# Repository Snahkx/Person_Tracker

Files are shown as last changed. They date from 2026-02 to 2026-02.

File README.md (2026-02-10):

# Real-Time Vision-Based Person Tracking with Pan–Tilt Control

This project is a hands-on exploration of real-time computer vision,
embedded control, and mechanical design. The system detects a human target
in a camera feed and physically reorients the camera using a pan–tilt
mechanism to keep the target centered.

It was built as an end-to-end system: from camera input, through control
logic, all the way to custom hardware.

---

Made in Collaboration with Ayrton Wong, AyrtonW312 on Github.

---

## Why This Project Exists

I wanted to build something that closed the loop between perception and
physical motion. Rather than stopping at detection on a screen, this
project forces the software to deal with the messiness of real hardware:
noise, latency, jitter, and failure modes.

The goal was not perfection, but understanding.

---

## What the System Does

- Captures live video on a Raspberry Pi
- Detects and tracks a human target
- Computes image-space error relative to the frame center
- Converts that error into pan–tilt servo commands
- Physically moves the camera to follow the target

All of this runs in real time on embedded hardware.

---

## System Structure

The system is organized into three layers:
- Vision (what do I see?)
- Control (how should I move?)
- Hardware (how do I move safely?)

Each layer is deliberately kept simple and isolated.

For details, see:
- [`docs/architecture.md`](docs/architecture.md)
- [`docs/design-decisions.md`](docs/design-decisions.md)

---

## Hardware

The camera is mounted on a custom-designed pan–tilt platform modeled in
SolidWorks. The design focuses on alignment, stiffness, and ease of
iteration using 3D-printed components.

📁 Hardware files, drawings, and assembly: [`hardware/`](hardware/)

---

## Validation

The system was tested on physical Raspberry Pi hardware with a servo-driven
pan–tilt platform. Testing focused on:
- Stability near the image center
- Smooth target reacquisition
- Safe behavior during target loss

---

## Current State

The core system is complete and documented. Demo media and annotated
screenshots will be added once hardware access is available.

---

## Future Directions

This project is intentionally extensible. Possible next steps include:
- Predictive filtering for smoother motion
- Multi-target tracking
- ROS2 integration
- Hardware acceleration for vision processing

https://ibrahimmansur4.medium.com/integrating-opencv-with-ros2-a-comprehensive-guide-to-computer-vision-in-robotics-66b97fa2de92

---

## Repo Guide

- `src/` – vision, control, and runtime code  
- `hardware/` – Files, drawings, and Assembly.
- `docs/` – architecture and design documentation  
- `demo/` – demo media (to be added)

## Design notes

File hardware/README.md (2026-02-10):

# Hardware Design – Pan–Tilt Tracking Platform

## Overview
This hardware system supports a camera-based real-time tracking pipeline by providing
a two-axis pan–tilt mechanism driven by SG90 servos. The design prioritizes stability,
repeatability, and ease of integration with Raspberry Pi-based control software.

## Components
- 2× SG90 servos (pan + tilt)
- Raspberry Pi camera module 
- Custom-designed 3D printed pan–tilt setup (SolidWorks)
- Fasteners (M3 hardware)
- Base mount (desk)

## Mechanical Architecture
The system consists of a fixed base, a pan stage driven by a horizontal-axis servo,
and a tilt stage mounted orthogonally to allow vertical tracking. The camera bracket
is aligned to minimize offset between optical axis and rotation axes.

## CAD Files
- Native SolidWorks files: `hardware/cad/`
- Neutral exports (STL): `hardware/exports/`
- Manufacturing drawings: `hardware/drawings/`

## Design Considerations
- Minimized backlash in servo mounts + DFA 
- Camera alignment to reduce control error + DFA
- Structural stiffness to limit vibration + DFA
- Fastener accessibility for rapid iteration + DFA

## Assembly
See exploded view for assembly below, schematics in other files.

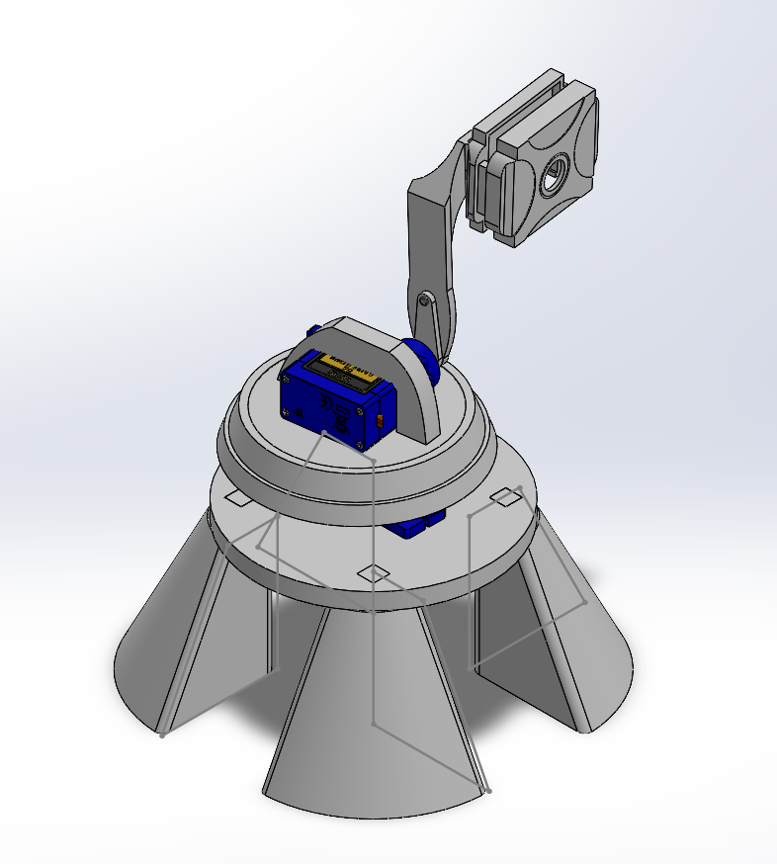
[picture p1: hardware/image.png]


## Future Improvements
- Bearing-supported pan axis
- Higher-torque digital servos
- Enclosure for cable management
- Vibration damping

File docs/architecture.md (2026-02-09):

# System Architecture

This document describes the high-level architecture of the real-time
vision-based tracking system, including subsystem boundaries, data flow,
and design rationale.

The system was intentionally structured to separate perception, control,
and hardware interaction, allowing each layer to be developed, tested,
and reasoned about independently.

---

## High-Level Overview

At a high level, the system operates as a closed-loop feedback controller:

1. Capture a video frame from the camera
2. Detect and localize a target in image space
3. Compute positional error relative to the image center
4. Convert error into pan–tilt motion commands
5. Actuate servos to reorient the camera
6. Repeat at real-time frequency

This loop runs continuously on Raspberry Pi hardware.

---

## Subsystem Decomposition

The system is divided into three primary subsystems:

- Vision Pipeline
- Control Layer
- Hardware Interface

Each subsystem has a clearly defined responsibility and communicates
through simple, explicit interfaces.

---

## Vision Pipeline

**Responsibility:**  
Convert raw camera frames into a target position in pixel coordinates.

**Key components:**
- Camera abstraction for frame acquisition
- Detection modules (person / face / colour)
- Target selection and bounding box extraction
- Overlay rendering for diagnostics

The vision pipeline outputs:
- Target centroid `(x, y)` in image space
- Bounding box dimensions
- A validity signal indicating whether a target is currently tracked

The pipeline is designed to be stateless between frames, which simplifies
debugging and allows tracking modes to be swapped without affecting
downstream control logic.

---

## Control Layer

**Responsibility:**  
Translate image-space error into stable, physically safe servo commands.

The control layer receives:
- Horizontal and vertical pixel error
- Target validity state

It outputs:
- Pan and tilt servo pulse-width updates

### Error Computation

Error is computed as the difference between the target centroid and the
image center. This representation is intuitive, camera-agnostic, and
directly maps to pan–tilt motion.

### Deadband Logic

A configurable deadband is applied around the image center to suppress
small corrections caused by detection noise. This prevents servo jitter
and oscillation when the target is already approximately centered.

### Rate Limiting and Smoothing

To avoid aggressive motion when the target is far from center, the control
layer scales movement based on error magnitude. Large errors result in
faster motion, while small errors result in slower, finer adjustments.

---

## Hardware Interface

**Responsibility:**  
Safely translate control commands into physical motion.

The hardware interface:
- Initializes the pigpio connection
- Configures servo pulse-width limits
- Enforces minimum and maximum travel bounds
- Provides a clean shutdown path

Hardware availability is treated as a runtime condition rather than a
compile-time assumption. If the pigpio daemon is unavailable, the system
fails gracefully without crashing the vision pipeline.

---

## Configuration Strategy

All tunable parameters (servo limits, deadband size, detection thresholds)
are centralized in configuration files.

This approach:
- Eliminates hard-coded constants
- Enables rapid tuning without code changes
- Allows environment-specific overrides
- Makes system behavior explicit and auditable

---

### Interface Contracts (What each layer guarantees)

- Vision → Control:
  - Provides `(dx, dy)` pixel error from frame center and a `valid` flag.
  - Guarantees coordinates are in image space using the same frame resolution.

- Control → Hardware:
  - Provides bounded PWM pulse widths (µs) for pan and tilt channels.
  - Guarantees safety limits are enforced before commanding servos.

- Hardware → Vision:
  - Motion changes camera orientation; vision loop compensates continuously.
  - No direct feedback from servos is assumed (open-loop actuation).
  
  ---

## Architecture Diagram (End-to-End)

```text
┌───────────────────────────────────────────────────────────────┐
│                         Operator / User                        │
│  - Launches runtime (python main.py)                           │
│  - Observes overlay + tuning feedback                          │
└───────────────────────────────────────────────────────────────┘
                          │  Launch / Config
                          ▼
┌───────────────────────────────────────────────────────────────┐
│                       Runtime: main.py                         │
│  Application Loop:                                              │
│  - frame = Camera.read()                                        │
│  - result = tracker.process(frame)                              │
│  - compute pixel error vs frame center                          │
│  - update PanTiltController (if enabled)                        │
│  - draw overlay diagnostics                                     │
└───────────────────────────────────────────────────────────────┘
                          │  Frame + detection results
                          ▼
┌───────────────────────────────────────────────────────────────┐
│                    Vision Subsystem (src/vision)               │
│  Camera                                                        │
│  - Pi Camera / USB capture                                     │
│  - resolution + FPS tuning                                     │
│                                                               │
│  Trackers (person / face / colour)                              │
│  - detection + bounding box extraction                          │
│  - target selection (single target)                             │
│  - outputs centroid (x,y), bbox, valid flag                     │
└───────────────────────────────────────────────────────────────┘
                          │  Pixel error (dx, dy)
                          ▼
┌───────────────────────────────────────────────────────────────┐
│                 Control Subsystem (src/servo)                  │
│  PanTiltController                                              │
│  - deadband (jitter suppression near center)                    │
│  - error → step/velocity mapping                                │
│  - rate limiting / smoothing for stability                      │
│  - enforces min/max pulse widths (safe bounds)                  │
│                                                               │
│  pigpio Interface                                               │
│  - connects to pigpio daemon                                    │
│  - sends PWM pulse widths to GPIO pins                          │
└───────────────────────────────────────────────────────────────┘
                          │  PWM (pulse width in µs)
                          ▼
┌───────────────────────────────────────────────────────────────┐
│                        Hardware Platform                        │
│  Pan Servo (Yaw)                 Tilt Servo (Pitch)             │
│  - horizontal rotation           - vertical rotation             │
│             \                         /                          │
│              \                       /                           │
│               ▼                     ▼                            │
│               Pan–Tilt Mechanical Assembly                       │
│        (SolidWorks CAD + drawings in /hardware)                  │
│                               │                                 │
│                               ▼                                 │
│                           Camera Mount                           │
└───────────────────────────────────────────────────────────────┘

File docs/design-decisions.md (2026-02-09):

# Design Decisions & Rationale

This document captures the key design decisions made during development,
including alternatives considered and tradeoffs accepted.

The goal is not to claim optimality, but to document reasoning.

---

## Choice of Platform: Raspberry Pi

The Raspberry Pi was selected as the target platform due to:
- Widespread availability
- Adequate performance for real-time vision tasks
- Direct GPIO access for servo control
- Strong ecosystem support
- Beginner introduction to bash, linux, and terminal cmds

Resource constraints influenced several downstream design decisions,
particularly around processing frequency and algorithm complexity.

---

## Vision Library: OpenCV

OpenCV was chosen for its:
- Mature and well-documented API
- Real-time performance on ARM platforms
- Broad support for classical vision techniques
- Ease of integration with Python
- Default Libraries

Deep learning–based detectors were intentionally avoided in the initial
implementation to reduce system complexity and hardware dependency.

---

## Control Strategy: Classical Feedback Control

A classical feedback control approach was chosen over more advanced
predictive methods.

Reasons:
- Transparent behavior that is easy to reason about
- Minimal tuning complexity
- Robustness to partial or noisy detections
- Suitability for low-latency embedded systems

This decision favored reliability and interpretability over theoretical
optimality.

---

## Deadband-Based Stabilization

Initial testing revealed servo jitter when the target hovered near the
image center. Rather than filtering detection output aggressively, a
deadband was introduced at the control level.

This approach:
- Directly addresses the symptom (micro-corrections)
- Preserves responsiveness for larger errors
- Simplifies tuning

---

## pigpio for Servo Control

pigpio was selected instead of software PWM due to:
- Hardware-timed pulse generation
- Reduced jitter under system load
- Precise pulse-width control

The dependency on a background daemon was accepted in exchange for
improved control stability.

---

## Modular Tracking Modes

Tracking modes (person, face, colour) were implemented as modular units
sharing a common interface.

This decision:
- Simplifies experimentation
- Avoids entangling detection logic with control logic
- Enables rapid switching without structural changes

---

## Configuration-Driven Design

Centralized configuration files were used to avoid embedding tuning
parameters directly in code.

Benefits:
- Faster iteration during testing
- Clear separation between logic and parameters
- Easier portability across hardware setups

---

## Error Handling Philosophy

Rather than failing loudly when hardware components are unavailable,
the system degrades gracefully.

This reflects a practical development reality: hardware is not always
available, but software iteration should continue regardless.

---

## Known Limitations

- No predictive tracking or velocity estimation
- Single-target assumption
- Limited robustness under extreme lighting conditions

These limitations were consciously accepted to prioritize system clarity
and stability.

---

## Reflection

Many of these decisions prioritize understandability and robustness over
maximum performance. This aligns with the project’s goal as a learning
platform and a foundation for future expansion rather than a production
deployment.

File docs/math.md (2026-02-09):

# Distance Estimation (Monocular)

This document describes how `DistanceEstimator` estimates the distance between
the camera and a tracked target using a **single monocular camera**. The approach
uses a pinhole camera approximation, one-time calibration, and exponential
smoothing for real-time stability.

---

## Signal Processing Pipeline

Goal: estimate distance to target (cm) from a detected bounding box width (px).

Camera Frame
↓
Target Detection / Tracking
↓
Bounding Box Width (px)
↓
Pinhole Distance Model
↓
Exponential Smoothing
↓
Distance Estimate (cm)

---

## Core Model: Pinhole Camera Approximation

The estimator assumes a pinhole camera model where the apparent width of an
object in the image is inversely proportional to its distance from the camera.

distance_cm = (known_width_cm * focal_length_px) / bbox_width_px

Where:
- `known_width_cm` = real-world width of the target (KNOWN_TARGET_WIDTH_CM)
- `focal_length_px` = camera focal length in pixel units (FOCAL_LENGTH_PX)
- `bbox_width_px` = observed bounding box width in pixels

Interpretation:
- Larger bounding box → target is closer
- Smaller bounding box → target is farther

---

## Calibration (Estimating Focal Length in Pixels)

Because focal length in pixel units depends on camera intrinsics and resolution,
it is estimated once using a known-distance calibration.

focal_length_px = (bbox_width_px * calib_distance_cm) / known_width_cm

Where:
- `calib_distance_cm` = known distance during calibration (CALIB_DISTANCE_CM)
- `bbox_width_px` = bounding box width measured at that distance
- `known_width_cm` = real-world target width

---

### Practical Calibration Procedure

1. Place the target at a known distance (e.g. 50 cm).
2. Run the tracker and measure `bbox_width_px`.
3. Call `calibrate(bbox_width_px)` once.
4. Store the resulting `FOCAL_LENGTH_PX` in the config for repeatable runs.

---

### Notes / Assumptions

- Assumes the target’s effective width is consistent and roughly planar to the camera.
- Changing camera resolution changes pixel focal length.
- Recalibrate if camera resolution or lens changes.

---

## Distance Estimation (Runtime)

Once calibrated, distance is computed every frame using the pinhole model:

raw_distance_cm = (known_width_cm * focal_length_px) / bbox_width_px

If focal length is unknown or `bbox_width_px <= 0`, the estimator returns `None`
to avoid invalid results.

---

## Smoothing (Low-Pass Filter)

Raw distance estimates fluctuate due to detection noise (lighting, occlusion,
bounding box jitter). To stabilize the output, exponential smoothing is applied.

smoothed_distance =
(1 - alpha) * previous_distance + alpha * current_distance

Where:
- `alpha` = smoothing factor (DIST_SMOOTH_ALPHA)
- Lower alpha → smoother but slower response
- Higher alpha → faster response but noisier

Implementation detail:
- On the first valid estimate, the smoothed value is initialized directly.

---

## Configuration Reference

| Parameter | Config Key | Default | Description |
|---|---|---|---|
| Target width (cm) | KNOWN_TARGET_WIDTH_CM | 16.0 | Assumed real-world target width |
| Calibration distance (cm) | CALIB_DISTANCE_CM | 50.0 | Known distance for calibration |
| Focal length (px) | FOCAL_LENGTH_PX | None | Computed once via calibration |
| Smoothing factor | DIST_SMOOTH_ALPHA | 0.25 | Exponential smoothing strength |

---

## Failure Conditions

The estimator returns `None` when:
- Focal length has not been calibrated
- Bounding box width is zero or invalid

This prevents divide-by-zero and meaningless distance values.

---

## Limitations

- Distance accuracy depends on the correctness of `known_width_cm`
- Bounding box width changes with target orientation (e.g. rotation)
- Monocular depth estimation is inherently approximate
- Not suitable for precise ranging or safety-critical decisions

Despite these limitations, the estimator provides a lightweight and
real-time distance approximation suitable for visualization and
coarse behavior logic.

---

## Future Improvements

- Height-based estimation (more stable for upright people)
- Keypoint-based distance instead of bounding box width
- Kalman filtering for predictive smoothing
- Multi-point calibration curve

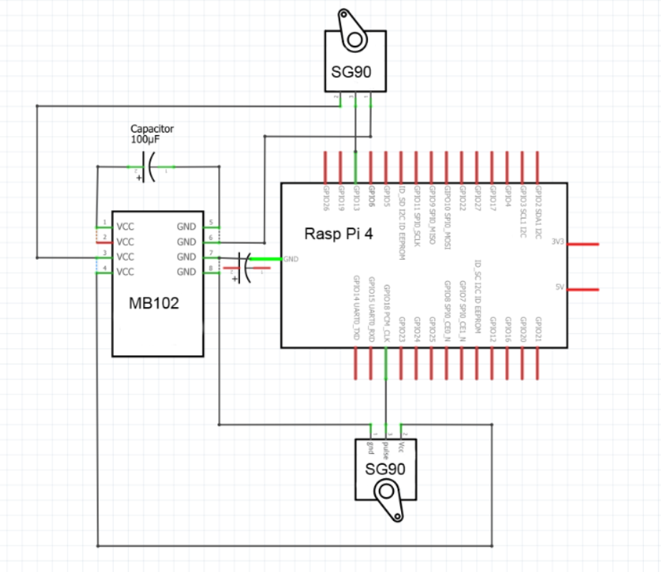
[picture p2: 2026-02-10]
hardware/wiring/schematic.png

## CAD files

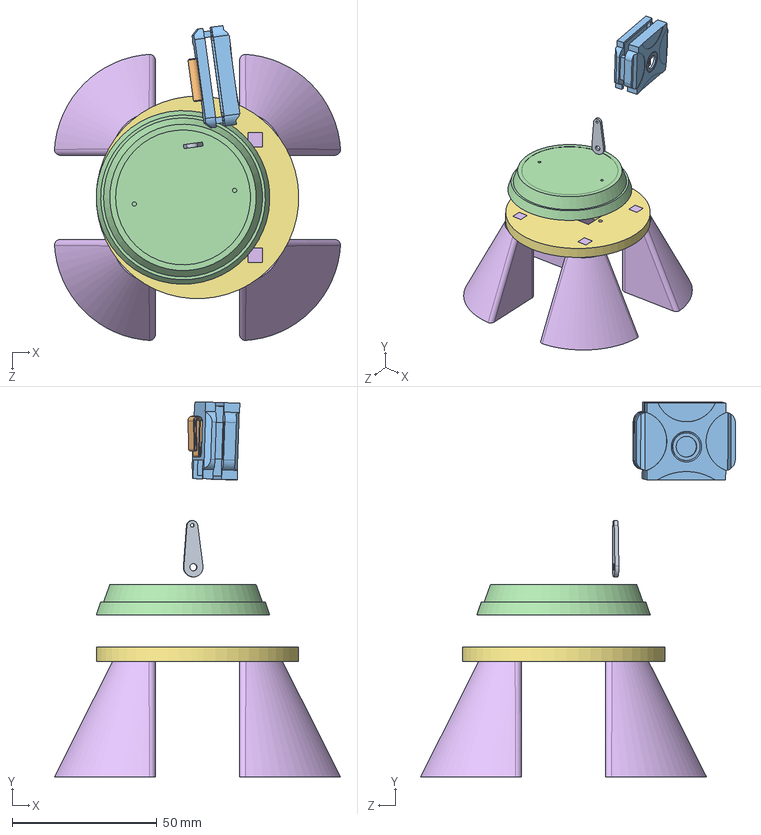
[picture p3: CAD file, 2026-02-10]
hardware/drawings/Assembly.SLDASM
98.9 x 129.6 x 108.8 mm
basePlateservo
legreal x 4
pimainWheel
surface2
cambox
camConnector
Servo Boomerang sg9

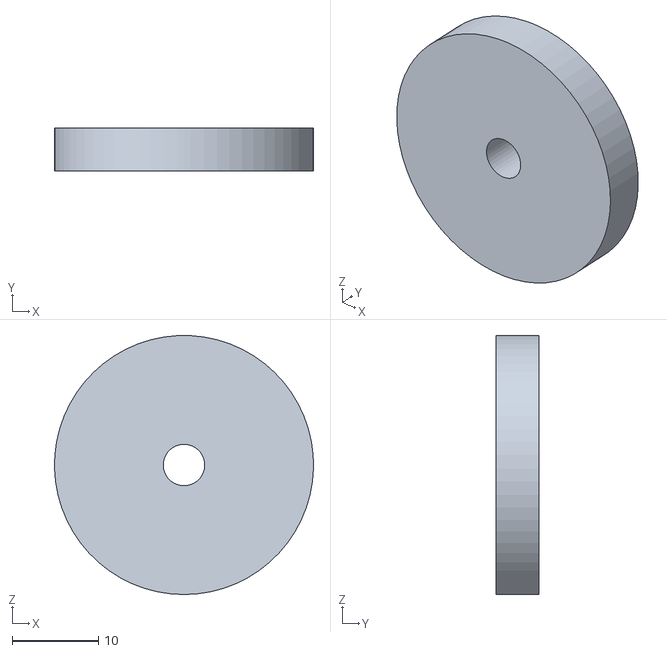
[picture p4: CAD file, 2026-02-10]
hardware/exports/pimainWheel.STL
30.0 x 5.00 x 30.0

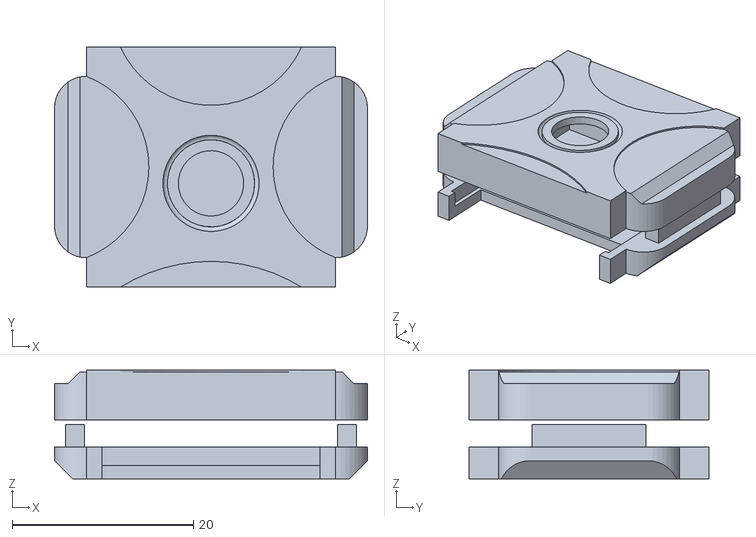
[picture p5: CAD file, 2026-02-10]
hardware/exports/cambox.STL
34.5 x 26.5 x 12.0

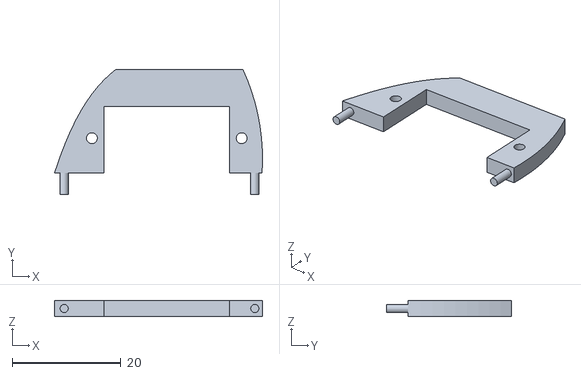
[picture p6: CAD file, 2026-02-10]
hardware/exports/handle.STL
38.2 x 23.0 x 3.00

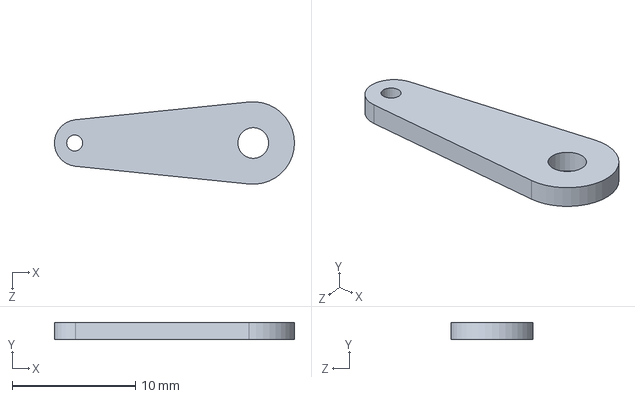
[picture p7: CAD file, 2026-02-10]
hardware/drawings/Servo Boomerang sg9.SLDPRT
19.5 x 1.40 x 6.69 mm

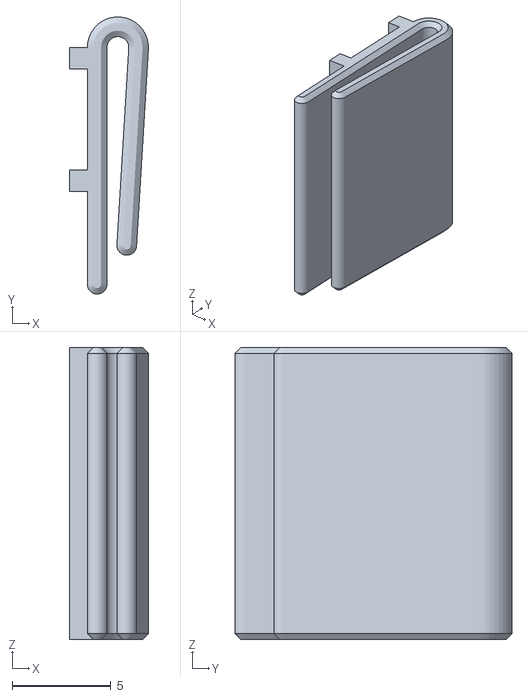
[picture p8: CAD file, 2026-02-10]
hardware/exports/camConnector.STL
4.00 x 14.0 x 14.8

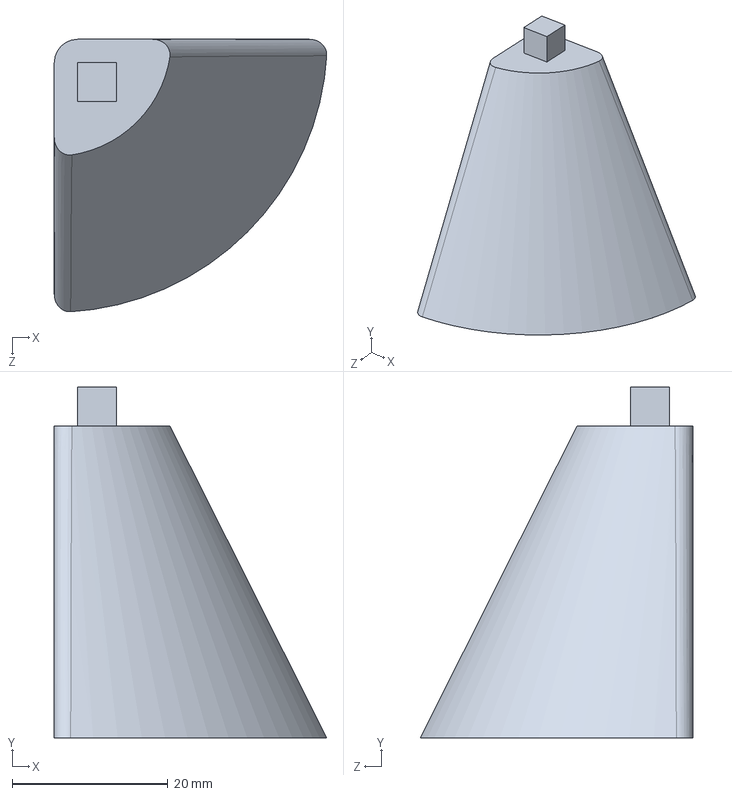
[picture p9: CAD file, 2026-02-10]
hardware/drawings/legreal.SLDPRT
34.9 x 45.0 x 34.9 mm

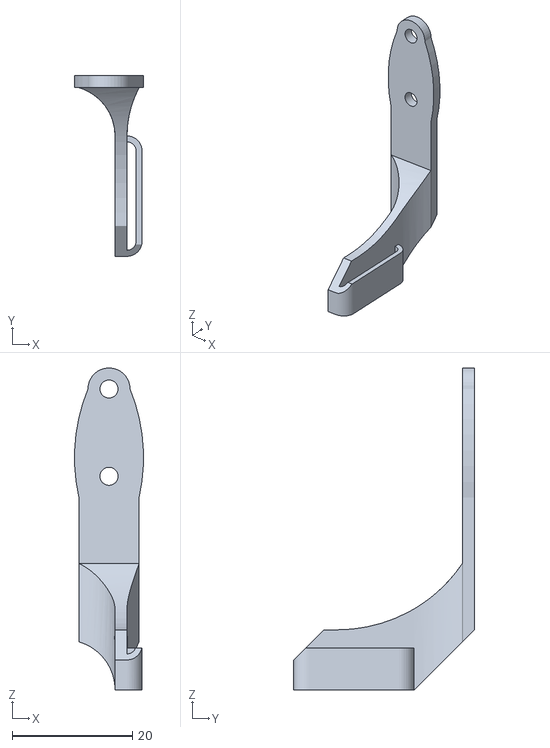
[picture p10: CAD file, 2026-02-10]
hardware/exports/piVertical.STL
11.4 x 30.0 x 53.5

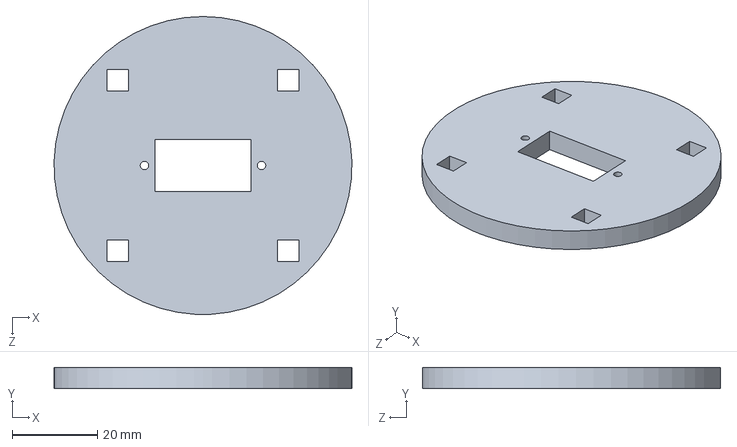
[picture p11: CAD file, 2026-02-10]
hardware/drawings/basePlateservo.SLDPRT
70.0 x 5.00 x 70.0 mm

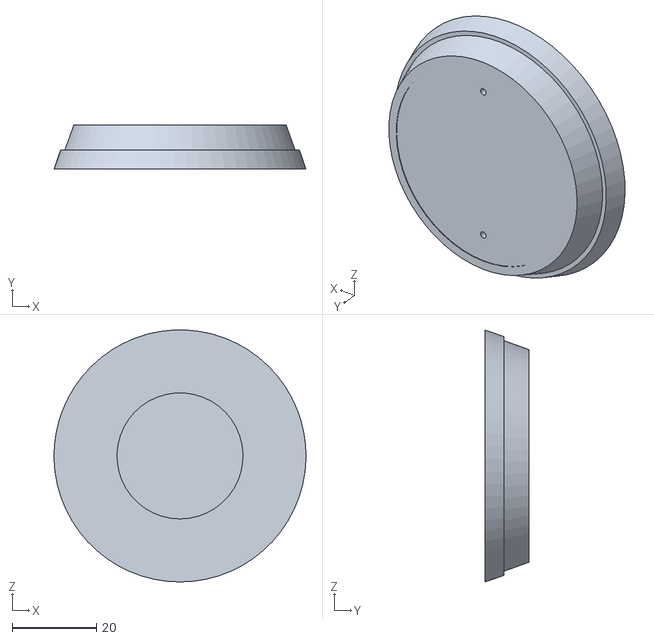
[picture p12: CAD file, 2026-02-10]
hardware/exports/surface2.STL
60.0 x 10.5 x 60.0

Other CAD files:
hardware/drawings/pimainWheel.SLDPRT
hardware/drawings/handle.SLDPRT
hardware/drawings/surface2.SLDPRT
hardware/drawings/cambox.SLDPRT
hardware/exports/Servo Boomerang sg9.STL
hardware/drawings/camConnector.SLDPRT
hardware/exports/basePlateservo.STL
hardware/exports/legreal.STL
hardware/drawings/piVertical.SLDPRT

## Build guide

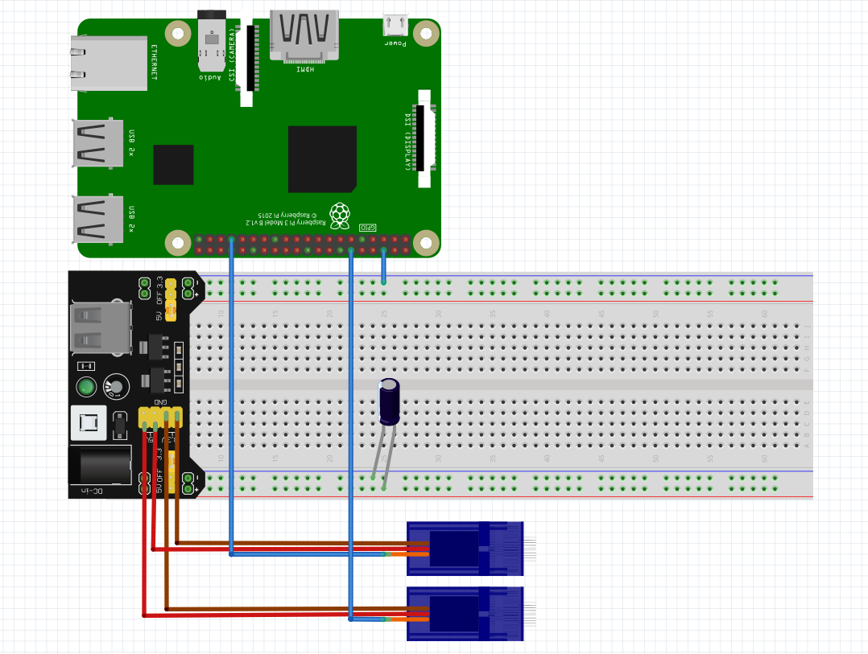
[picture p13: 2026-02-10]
hardware/wiring/breadboard.png

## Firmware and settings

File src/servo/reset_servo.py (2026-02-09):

# reset_servos.py
import time
import pigpio
import config
from servo.servos import Servo


def main():
    pi = pigpio.pi()
    if not pi.connected:
        raise RuntimeError(
            "pigpio daemon not running. Start with:\n"
            "sudo systemctl start pigpiod"
        )

    try:
        # Create servo objects
        pan = Servo(
            pi=pi,
            pin=config.PAN_PIN,
            us_min=config.PAN_US_MIN,
            us_max=config.PAN_US_MAX,
            us_center=config.PAN_US_CENTER,
        )

        tilt = Servo(
            pi=pi,
            pin=config.TILT_PIN,
            us_min=config.TILT_US_MIN,
            us_max=config.TILT_US_MAX,
            us_center=config.TILT_US_CENTER,
        )

        print("[INFO] Resetting servos to center...")

        # Explicitly set to center (in case they drifted)
        pan.set_us(config.PAN_US_CENTER)
        tilt.set_us(config.TILT_US_CENTER)

        # Give servos time to physically move
        time.sleep(0.8)

    finally:
        # Stop pulses so servos don't buzz
        pan.stop()
        tilt.stop()
        pi.stop()
        print("[INFO] Servos reset and released.")


if __name__ == "__main__":
    main()

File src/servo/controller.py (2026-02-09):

# servo/controller.py
import time
import pigpio
import config
from .servos import Servo



def clamp(v, vmin, vmax):
    return max(vmin, min(vmax, v))


class PanTiltController:
    """
    Mid-level control: error -> servo pulse width updates (pigpio).

    Changes vs your version:
    - Adds a "slow zone" so it moves fast when far away, but slows down near center
      to prevent overshoot/oscillation.
    - Keeps the same public API: update(error_x, error_y), close()
    """

    def __init__(self):
        self.pi = pigpio.pi()
        if not self.pi.connected:
            raise RuntimeError(
                "pigpio daemon not running (start with: sudo systemctl start pigpiod)"
            )

        self.pan = Servo(
            pi=self.pi,
            pin=config.PAN_PIN,
            us_min=config.PAN_US_MIN,
            us_max=config.PAN_US_MAX,
            us_center=config.PAN_US_CENTER,
        )

        self.tilt = Servo(
            pi=self.pi,
            pin=config.TILT_PIN,
            us_min=config.TILT_US_MIN,
            us_max=config.TILT_US_MAX,
            us_center=config.TILT_US_CENTER,
        )

        self._last_update = 0.0
        self._pan_acc = 0.0
        self._tilt_acc = 0.0


    def _scaled_max_step(self, error_x: int, error_y: int) -> float:
        mag = max(abs(error_x), abs(error_y))

        # Start fast when far
        scale = 1.2
        if mag > 250:
            scale = 1.6   # was 1.4
        elif mag > 150:
            scale = 1.2   # was 1.0
        elif mag > 80:
            scale = 0.7   # was 0.6
        else:
            scale = 0.40  # was 0.35
        return max(4, config.SERVO_MAX_STEP_US * scale)

    def update(self, error_x: int, error_y: int):
        now = time.time()
        if now - self._last_update < config.SERVO_UPDATE_S:
            return
        self._last_update = now

        if error_x == 0 and error_y == 0:
            return

        # Convert pixel error -> microsecond delta (proportional)
        d_pan = config.SERVO_KP_PAN * error_x
        d_tilt = config.SERVO_KP_TILT * error_y

        # Cap per update, with slow-zone scaling near center
        max_step = self._scaled_max_step(error_x, error_y)
        d_pan = clamp(d_pan, -max_step, max_step)
        d_tilt = clamp(d_tilt, -max_step, max_step)

        # Direction flips
        if config.PAN_INVERT:
            d_pan = -d_pan
        if config.TILT_INVERT:
            d_tilt = -d_tilt

        # Apply: subtracting generally moves toward reducing error
        # Accumulate fractional deltas so tiny movements still happen
        self._pan_acc += d_pan
        self._tilt_acc += d_tilt

        step_pan = int(round(self._pan_acc))
        step_tilt = int(round(self._tilt_acc))

        self._pan_acc -= step_pan
        self._tilt_acc -= step_tilt

        self.pan.set_us(self.pan.us - step_pan)
        self.tilt.set_us(self.tilt.us - step_tilt)


    def close(self):
        self.pan.stop()
        self.tilt.stop()
        self.pi.stop()

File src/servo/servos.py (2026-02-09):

# servo/servos.py
import pigpio

def clamp(v, vmin, vmax):
    return max(vmin, min(vmax, v))

class Servo:
    """
    Low-level pigpio servo driver.
    Uses pulse width in microseconds (µs).
    """

    def __init__(self, pi: pigpio.pi, pin: int, us_min: int, us_max: int, us_center: int):
        self.pi = pi
        self.pin = pin
        self.us_min = int(us_min)
        self.us_max = int(us_max)
        self.us = int(us_center)

        # Start at center
        self.set_us(self.us)

    def set_us(self, us: int):
        self.us = int(clamp(us, self.us_min, self.us_max))
        self.pi.set_servo_pulsewidth(self.pin, self.us)

    def stop(self):
        # 0 disables servo pulses
        self.pi.set_servo_pulsewidth(self.pin, 0)
